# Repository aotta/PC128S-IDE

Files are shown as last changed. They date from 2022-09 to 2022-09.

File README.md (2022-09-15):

# PC128S-IDE
An IDE interface for Olivetti Prodest PC128S & Master Compact
Further info on stardot.org.uk
Some note for soldering:
the Edge pin 10 doesn't need to be connected, it was for experimenting 1 mhz port, but it didn't work with ide drive. So, you can solder a link for 2mhz in j4 between pin 2 and 3, and avoid the jumper.
Note it's needed the 74HCxx series, not the 74LSxx one.
Remind to solder the connector edge slot in the right way (soldering from component side, not the solder side!)

Feel free to improve or change the boards, and my credits to J.G. Harston for original schemes ( https://mdfs.net/Info/Comp/BBC/IDE/ ) 

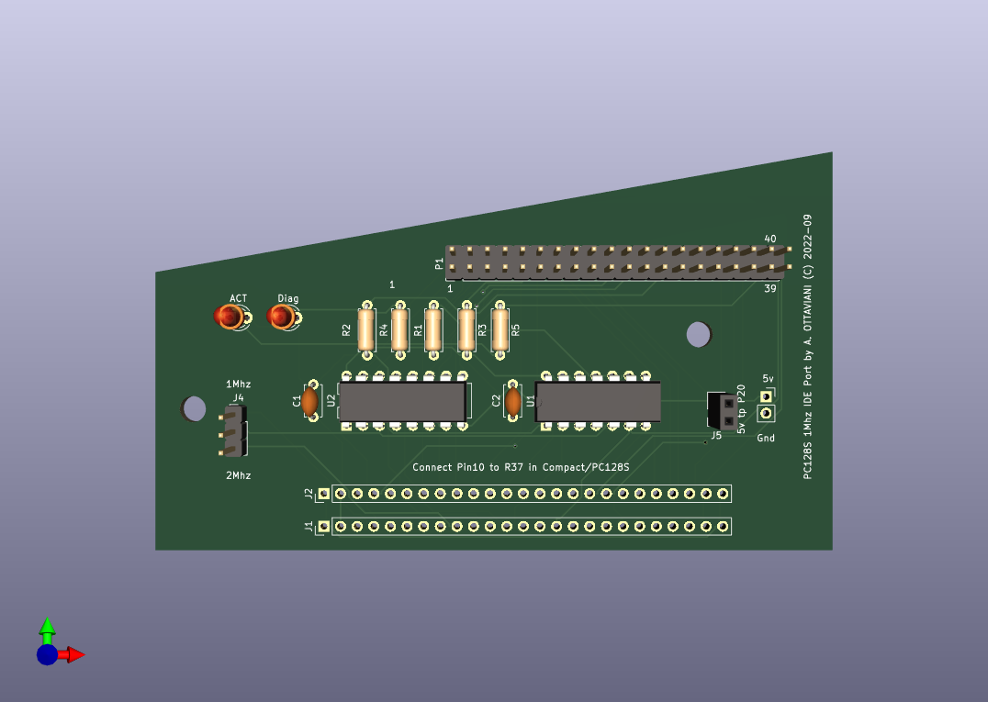
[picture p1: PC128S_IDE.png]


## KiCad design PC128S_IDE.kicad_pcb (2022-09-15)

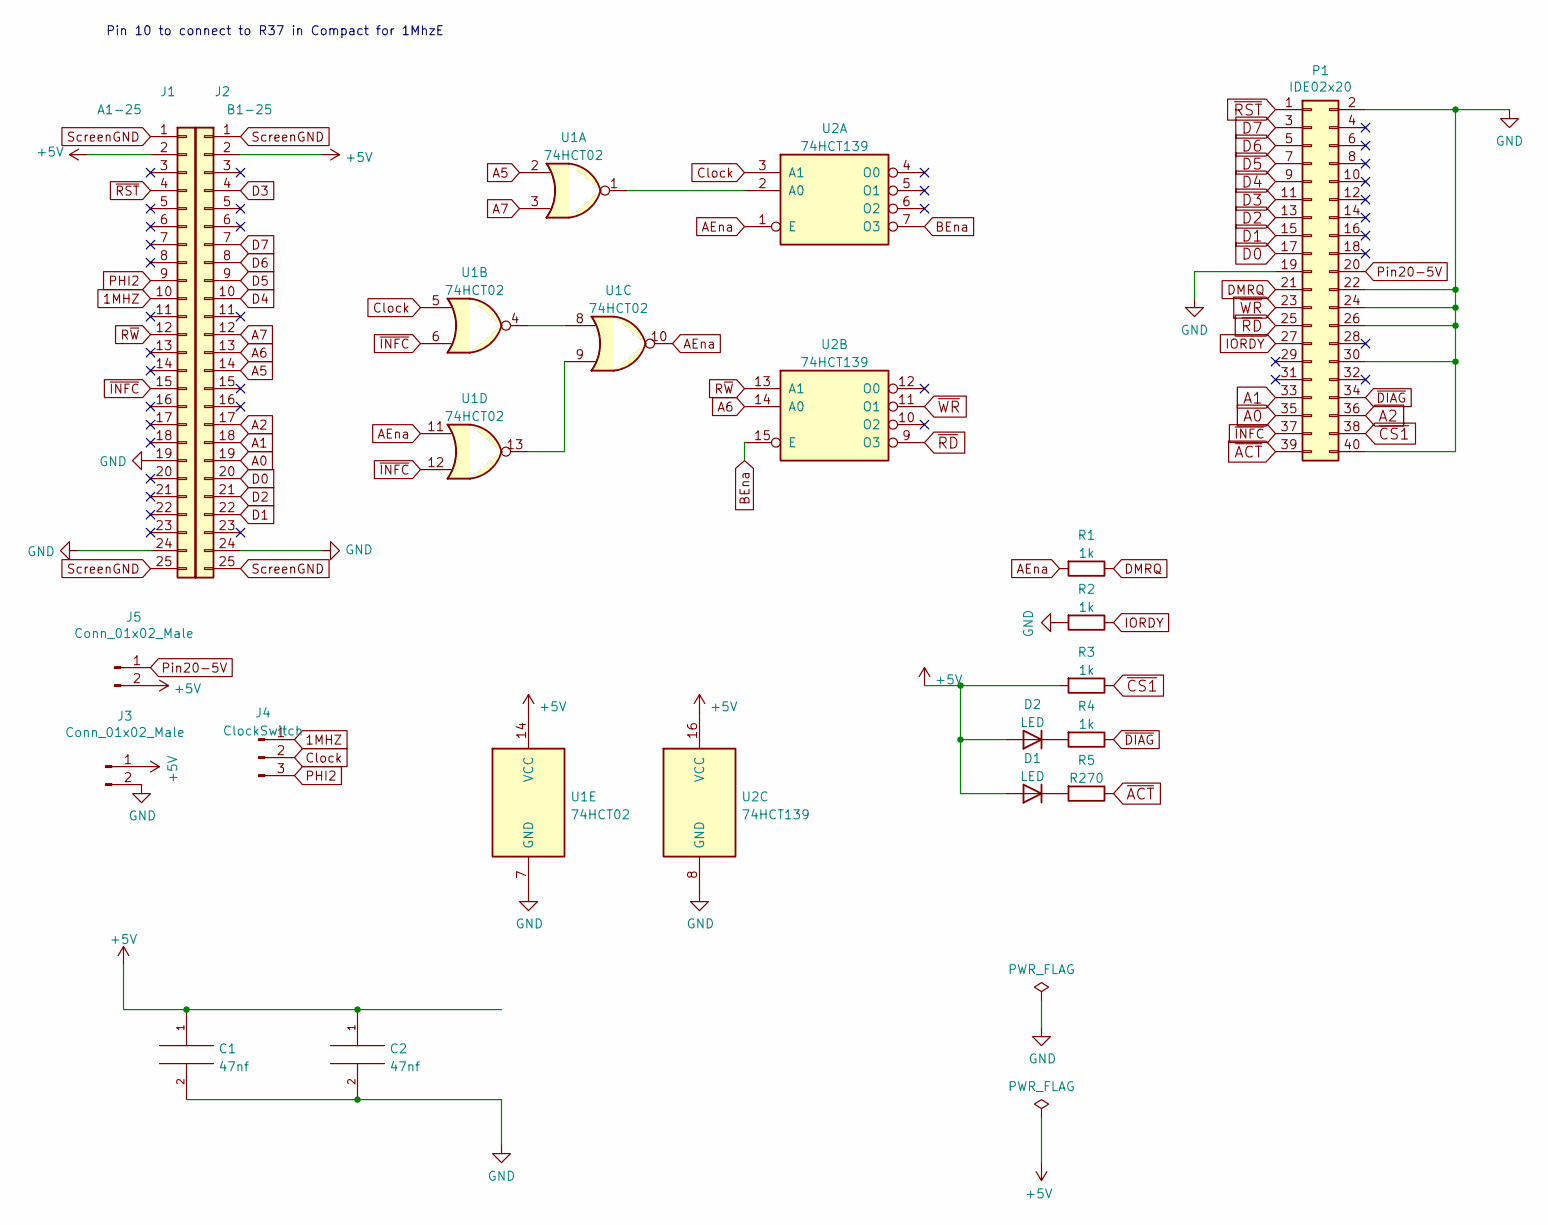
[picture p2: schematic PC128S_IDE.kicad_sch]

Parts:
C1, C2: 47nf; C_Disc_D4.7mm_W2.5mm_P5.00mm
D1, D2: LED; LED_D3.0mm
J1: A1-25; PinHeader_1x25_P2.54mm_Vertical
J2: B1-25; PinHeader_1x25_P2.54mm_Vertical
J3, J5: Conn_01x02_Male; PinSocket_1x02_P2.54mm_Vertical
J4: ClockSwitch; PinHeader_1x03_P2.54mm_Vertical
P1: IDE02x20; PinHeader_2x20_P2.54mm_Vertical
R1, R2, R3, R4: 1k; R_Axial_DIN0207_L6.3mm_D2.5mm_P7.62mm_Horizontal
R5: R270; R_Axial_DIN0207_L6.3mm_D2.5mm_P7.62mm_Horizontal
U1: 74HCT02; DIP-14_W7.62mm
U2: 74HCT139; DIP-16_W7.62mm

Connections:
1MHZ: J1.10, J4.1
+5V: C1.1, C2.1, D1.2 (A), D2.2 (A), J1.2, J2.2, J3.1, J5.2, R3.2, U1.14 (VCC), U2.16 (VCC)
A0: J2.19, P1.35
A1: J2.18, P1.33
A2: J2.17, P1.36
A5: J2.14, U1.2
A6: J2.13, U2.14 (A0)
A7: J2.12, U1.3
AEna: R1.2, U1.10, U1.11, U2.1 (E)
BEna: U2.7 (O3), U2.15 (E)
Clock: J4.2, U1.5, U2.3 (A1)
D0: J2.20, P1.17
D1: J2.22, P1.15
D2: J2.21, P1.13
D3: J2.4, P1.11
D4: J2.10, P1.9
D5: J2.9, P1.7
D6: J2.8, P1.5
D7: J2.7, P1.3
DMRQ: P1.21, R1.1
GND: C1.2, C2.2, J1.19, J1.24, J2.24, J3.2, P1.2, P1.19, P1.22, P1.24, P1.26, P1.30, P1.40, R2.2, U1.7 (GND), U2.8 (GND)
IORDY: P1.27, R2.1
unnamed: D1.1 (K), R5.2
unnamed: D2.1 (K), R4.2
unnamed: U1.1, U2.2 (A0)
unnamed: U1.4, U1.8
unnamed: U1.9, U1.13
PHI2: J1.9, J4.3
Pin20-5V: J5.1, P1.20
R~W: J1.12, U2.13 (A1)
ScreenGND: J1.1, J1.25, J2.1, J2.25
~ACT: P1.39, R5.1
~CS1: P1.38, R3.1
~DIAG: P1.34, R4.1
~INFC: J1.15, P1.37, U1.6, U1.12
~RD: P1.25, U2.9 (O3)
~RST: J1.4, P1.1
~WR: P1.23, U2.11 (O1)

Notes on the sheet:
Pin 10 to connect to R37 in Compact for 1MhzE

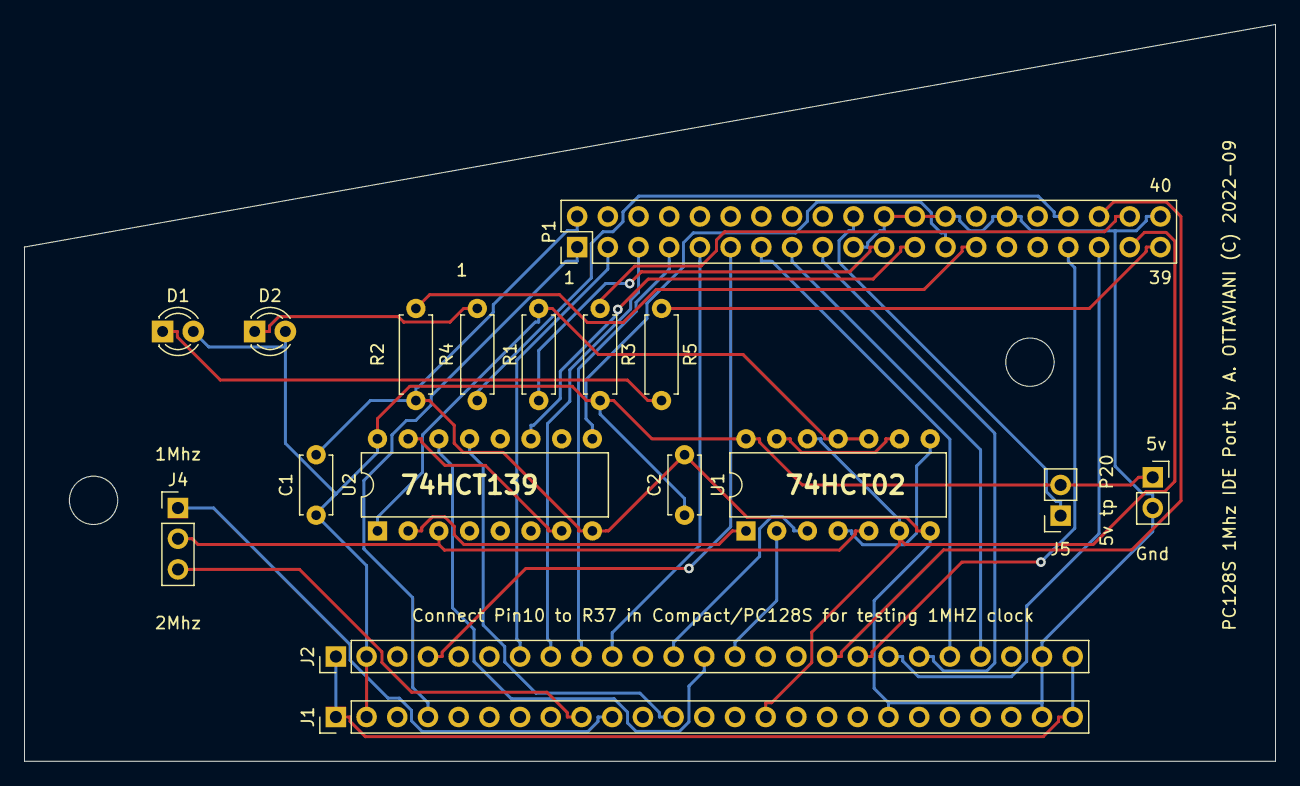
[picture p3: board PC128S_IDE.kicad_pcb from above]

Board: 2 copper layers, 103.5 x 61.0 mm, 17 parts (0 on the bottom side), 38 nets.

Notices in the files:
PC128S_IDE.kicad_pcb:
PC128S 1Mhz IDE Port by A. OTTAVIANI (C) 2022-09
